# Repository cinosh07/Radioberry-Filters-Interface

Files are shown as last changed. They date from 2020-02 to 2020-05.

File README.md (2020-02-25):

# Radioberry beta V3 - Filters Interface companion module.

Radioberry project
https://github.com/pa3gsb/Radioberry-2.x

This project interface LPF, HPF and T/R Switch to the radiobery I/O over i2c.
The logic is arduino nano v3 based microcontroller.

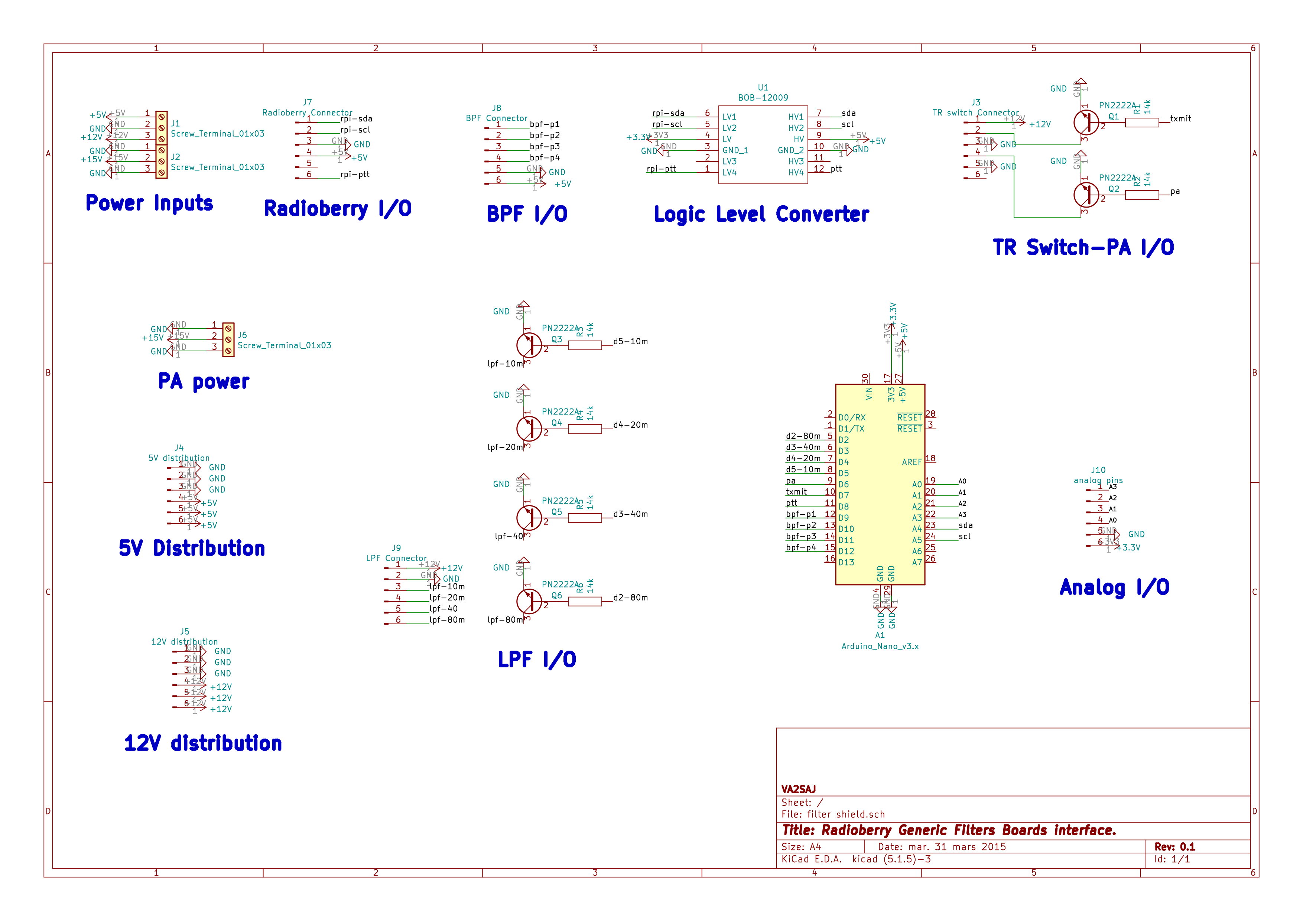
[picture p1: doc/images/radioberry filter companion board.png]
schema


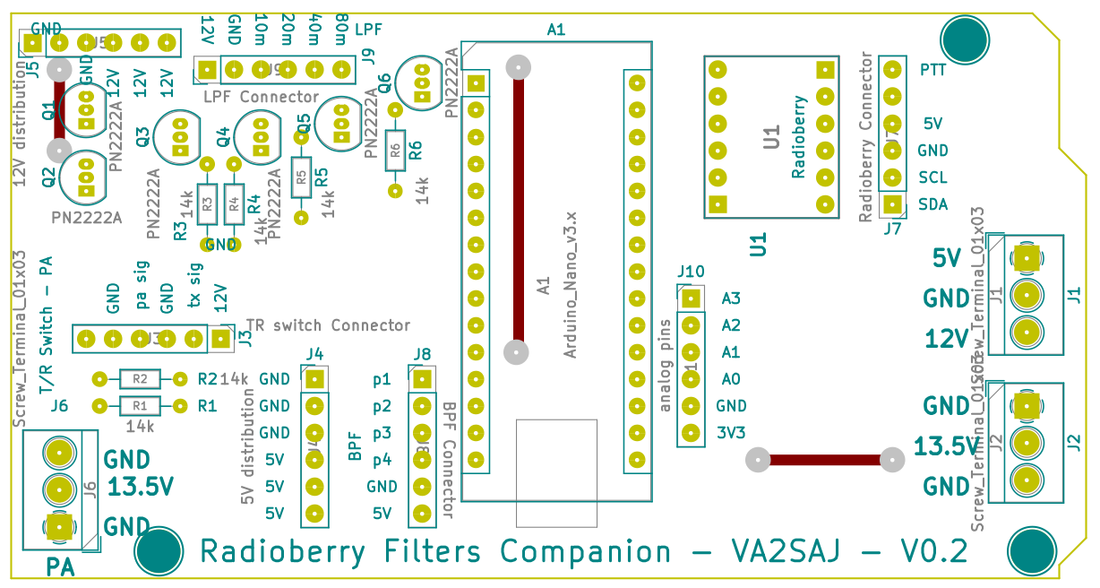
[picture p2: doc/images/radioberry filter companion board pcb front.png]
PCB TOP


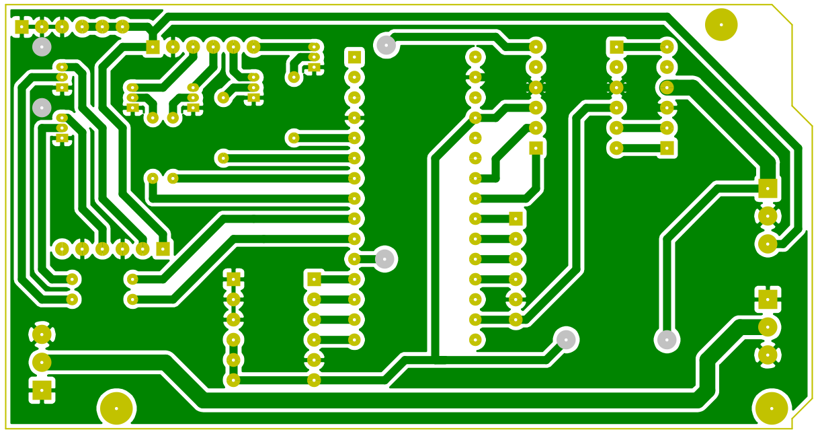
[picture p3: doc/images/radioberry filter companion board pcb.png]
PCB BACK


Band pass filters module supported:
https://www.ebay.ca/itm/HF-BPF-band-pass-filter-RTL-SDR-HERMES-ODYSSEY-HiQSDR-Red-Pitaya-transceiver/332074659425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

Low pass filters module supported:
https://www.ebay.ca/itm/12v-100W-3-5Mhz-30Mhz-HF-power-amplifier-low-pass-filter-Diy-kit/113761898910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

T/R Switch module supported:
https://www.qrpkits.com/ezseries.html#eztrsw

Auto Antenna tuner supported:
https://www.ebay.ca/itm/KIT-DIY-Automatic-Antenna-Tuner-7x7-ATU-100-mini-by-N7DDC/202740242392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

Linear PA supported:
https://www.qrp-labs.com/linear.html

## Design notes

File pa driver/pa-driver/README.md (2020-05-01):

# Radioberry beta V3 RPI4 - 9db PA Driver Module.

Radioberry project
https://github.com/pa3gsb/Radioberry-2.x

This allow to amplify the RPI4 radioberry version TX output, to suitable level for 10W QRP Labs Linear Power Amplifier.

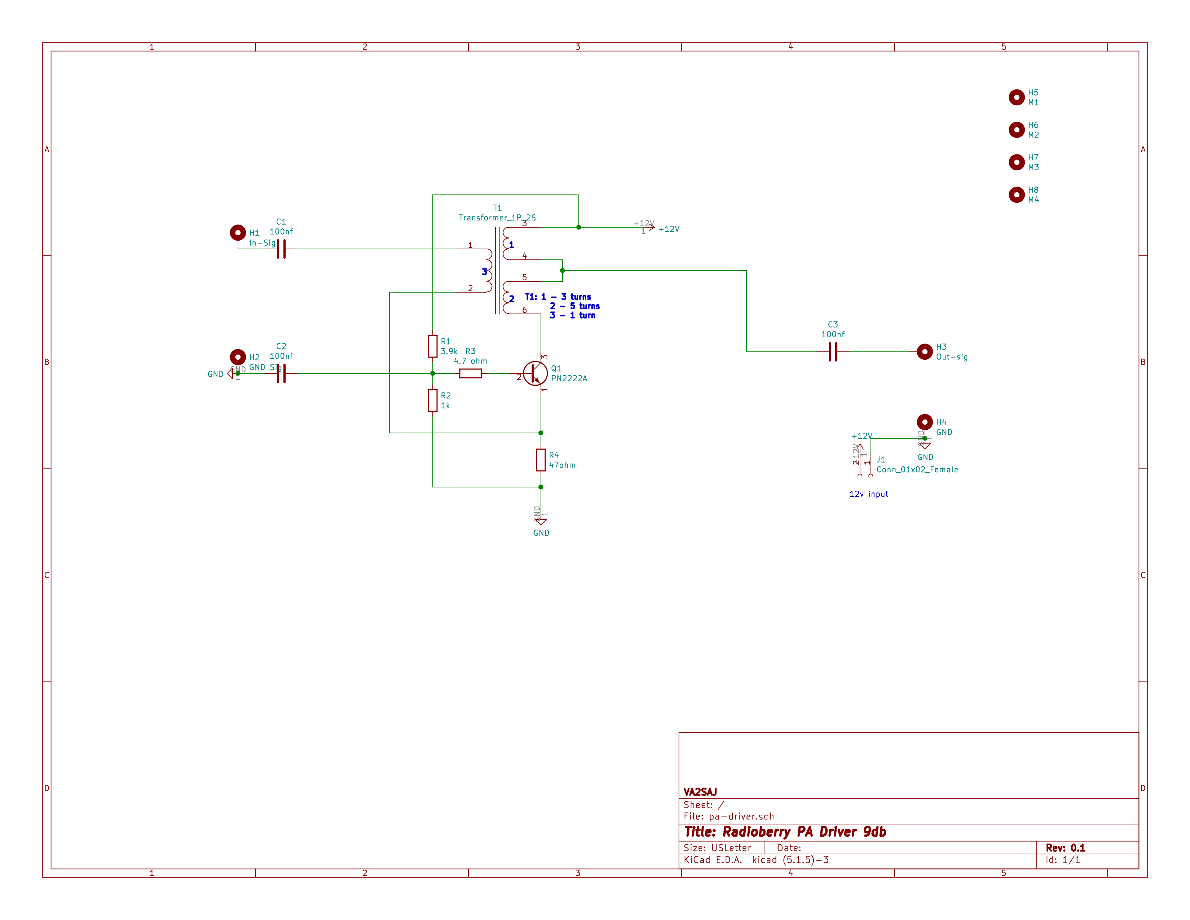
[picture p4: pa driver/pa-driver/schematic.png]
schema


Mesurement.

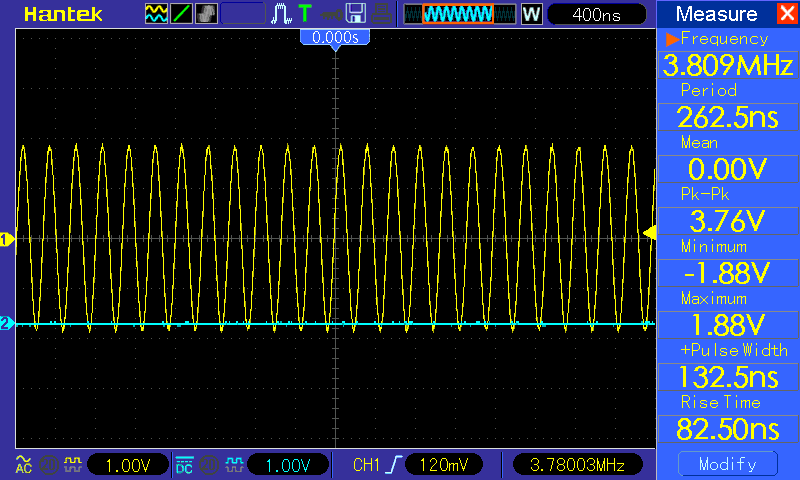
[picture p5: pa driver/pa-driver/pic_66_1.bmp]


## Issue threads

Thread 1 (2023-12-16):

program not working correctly

PE1PWR, 2023-12-16:
Hi m8,
Thanks for sharing your program and PCB board.
Ik have built already the radioberry and controller from Dileep.
My problem is when I connect a hermes on to the Nano I get not the right signals.
160m 0010
80m   0010
40m   0011
30m   0100
20m   0101
17m   0110
15m   0111
12m   0010
10m   0010
160,80,12 and 10m are the same bits so this is not working for the BPF filter board.
Is it so that the ino file on github is not complete? Or must I do something else to get the right signals. I am using the PIHPSDR from Dileep
[VU2DLE/Radioberry_Console: piHPSDR Controller. Is this the right version for your design. I hope you get a solution for me to finish my radioberry project.

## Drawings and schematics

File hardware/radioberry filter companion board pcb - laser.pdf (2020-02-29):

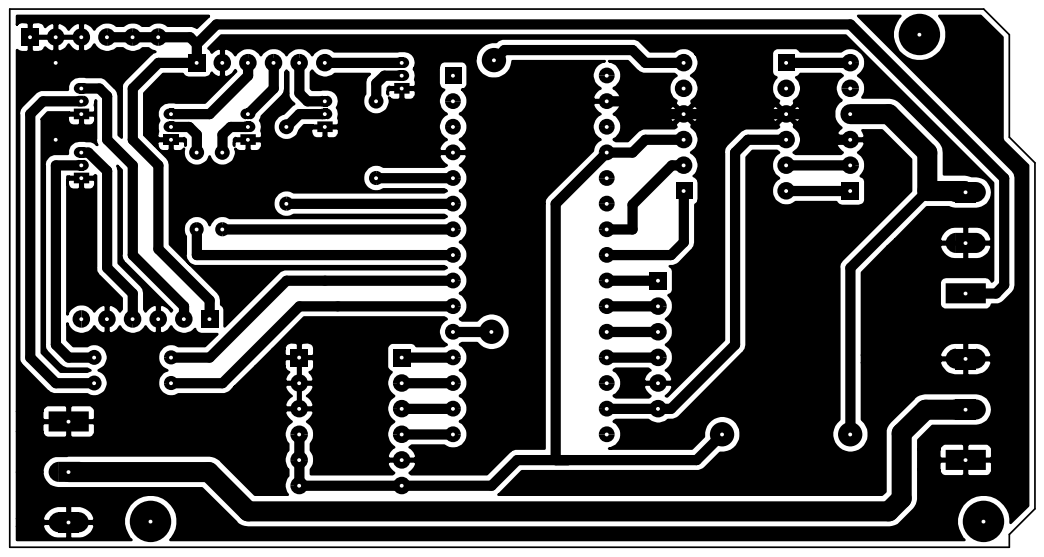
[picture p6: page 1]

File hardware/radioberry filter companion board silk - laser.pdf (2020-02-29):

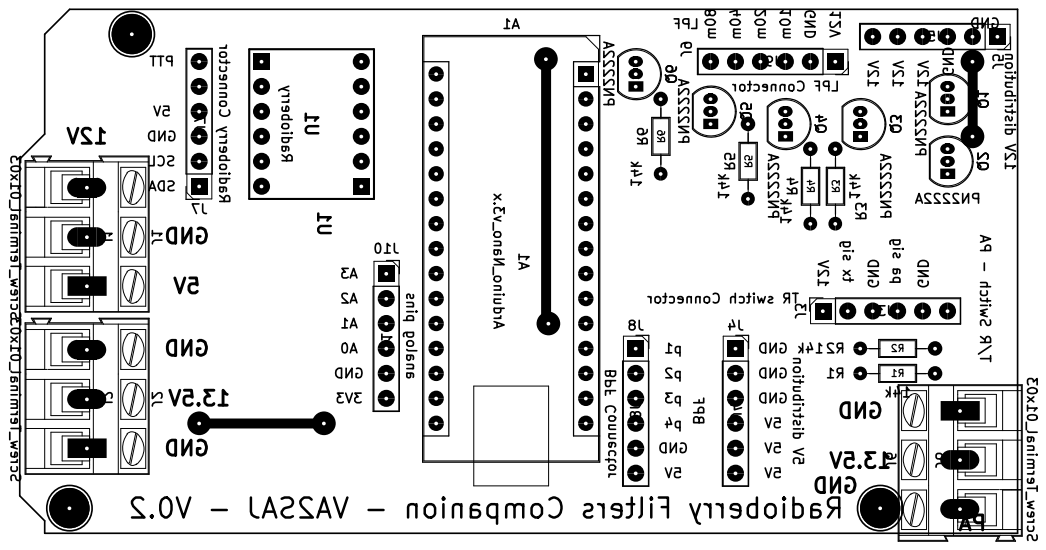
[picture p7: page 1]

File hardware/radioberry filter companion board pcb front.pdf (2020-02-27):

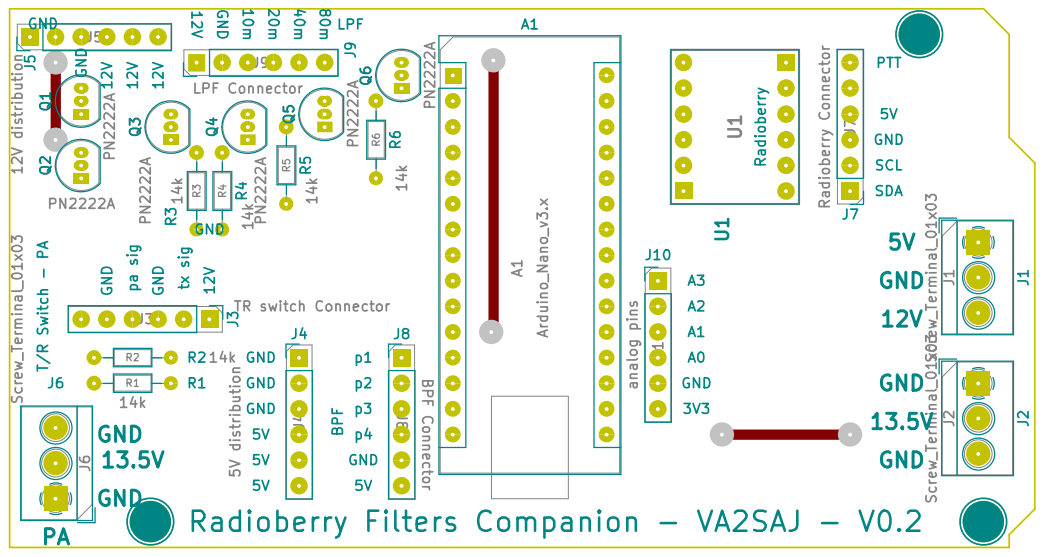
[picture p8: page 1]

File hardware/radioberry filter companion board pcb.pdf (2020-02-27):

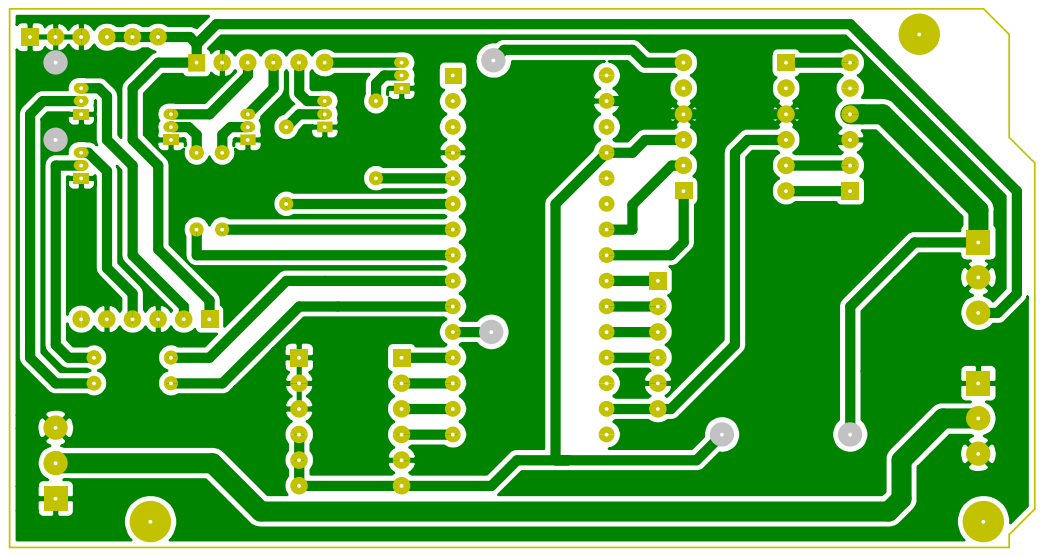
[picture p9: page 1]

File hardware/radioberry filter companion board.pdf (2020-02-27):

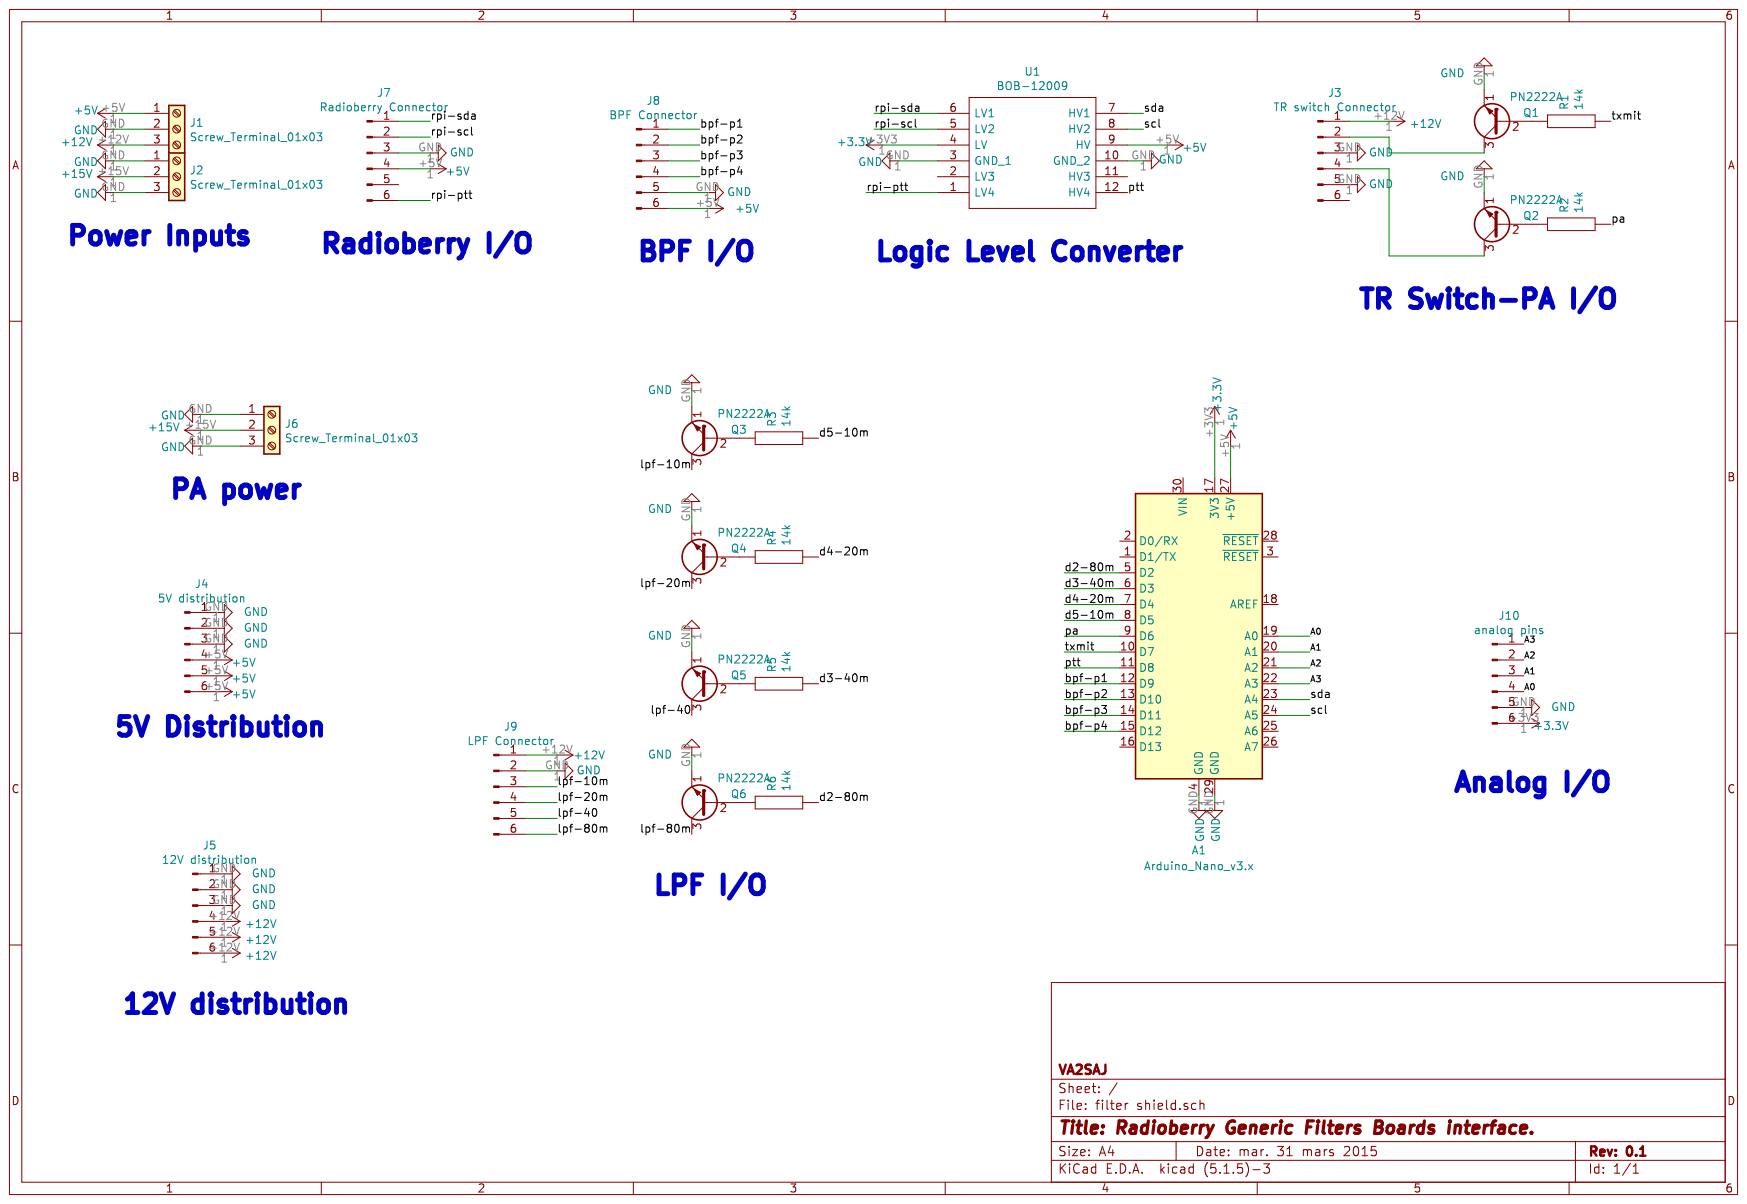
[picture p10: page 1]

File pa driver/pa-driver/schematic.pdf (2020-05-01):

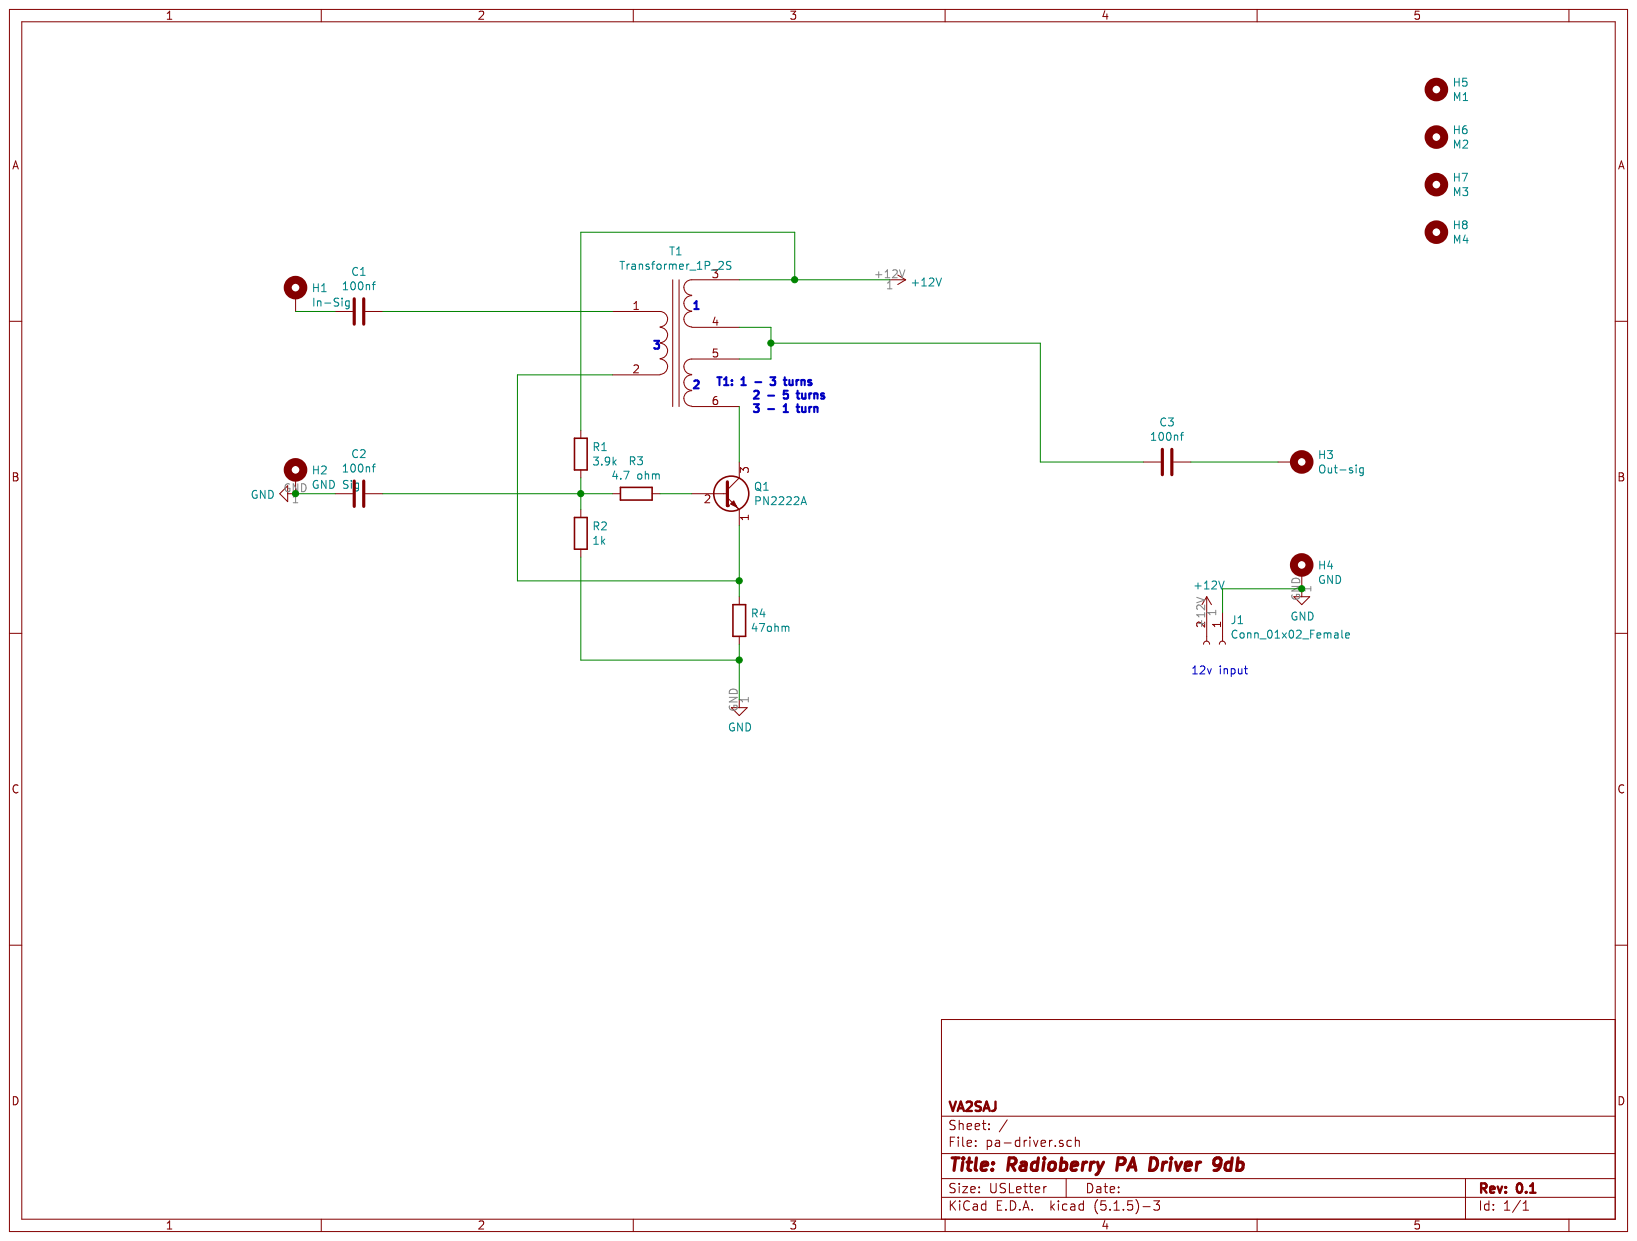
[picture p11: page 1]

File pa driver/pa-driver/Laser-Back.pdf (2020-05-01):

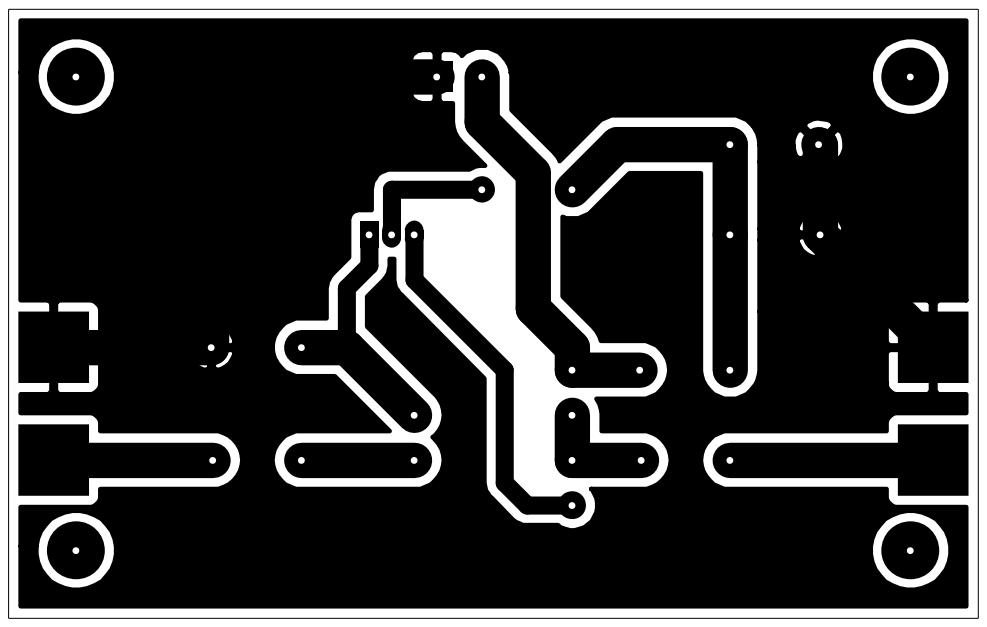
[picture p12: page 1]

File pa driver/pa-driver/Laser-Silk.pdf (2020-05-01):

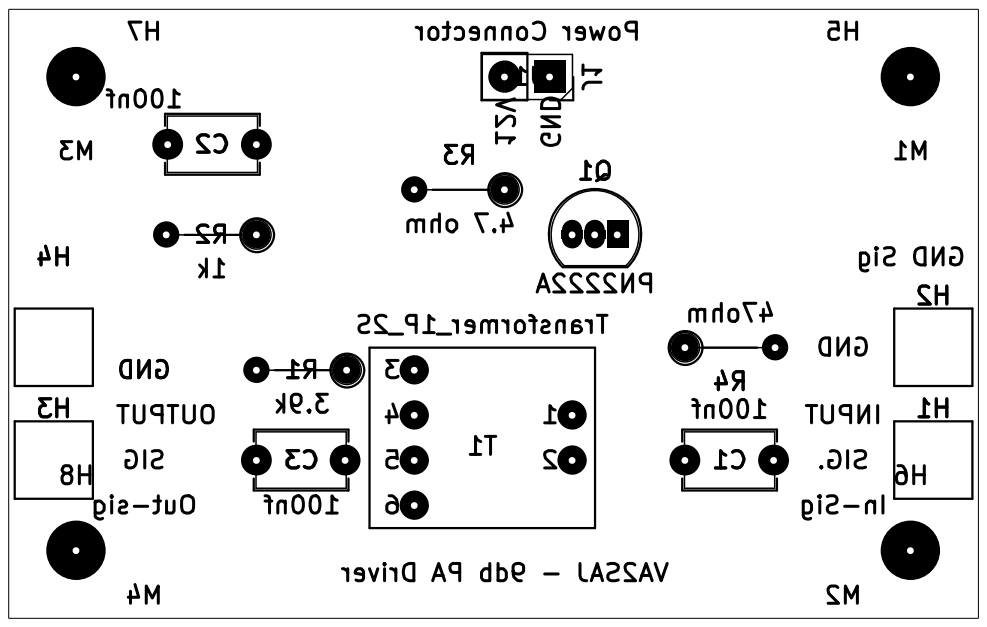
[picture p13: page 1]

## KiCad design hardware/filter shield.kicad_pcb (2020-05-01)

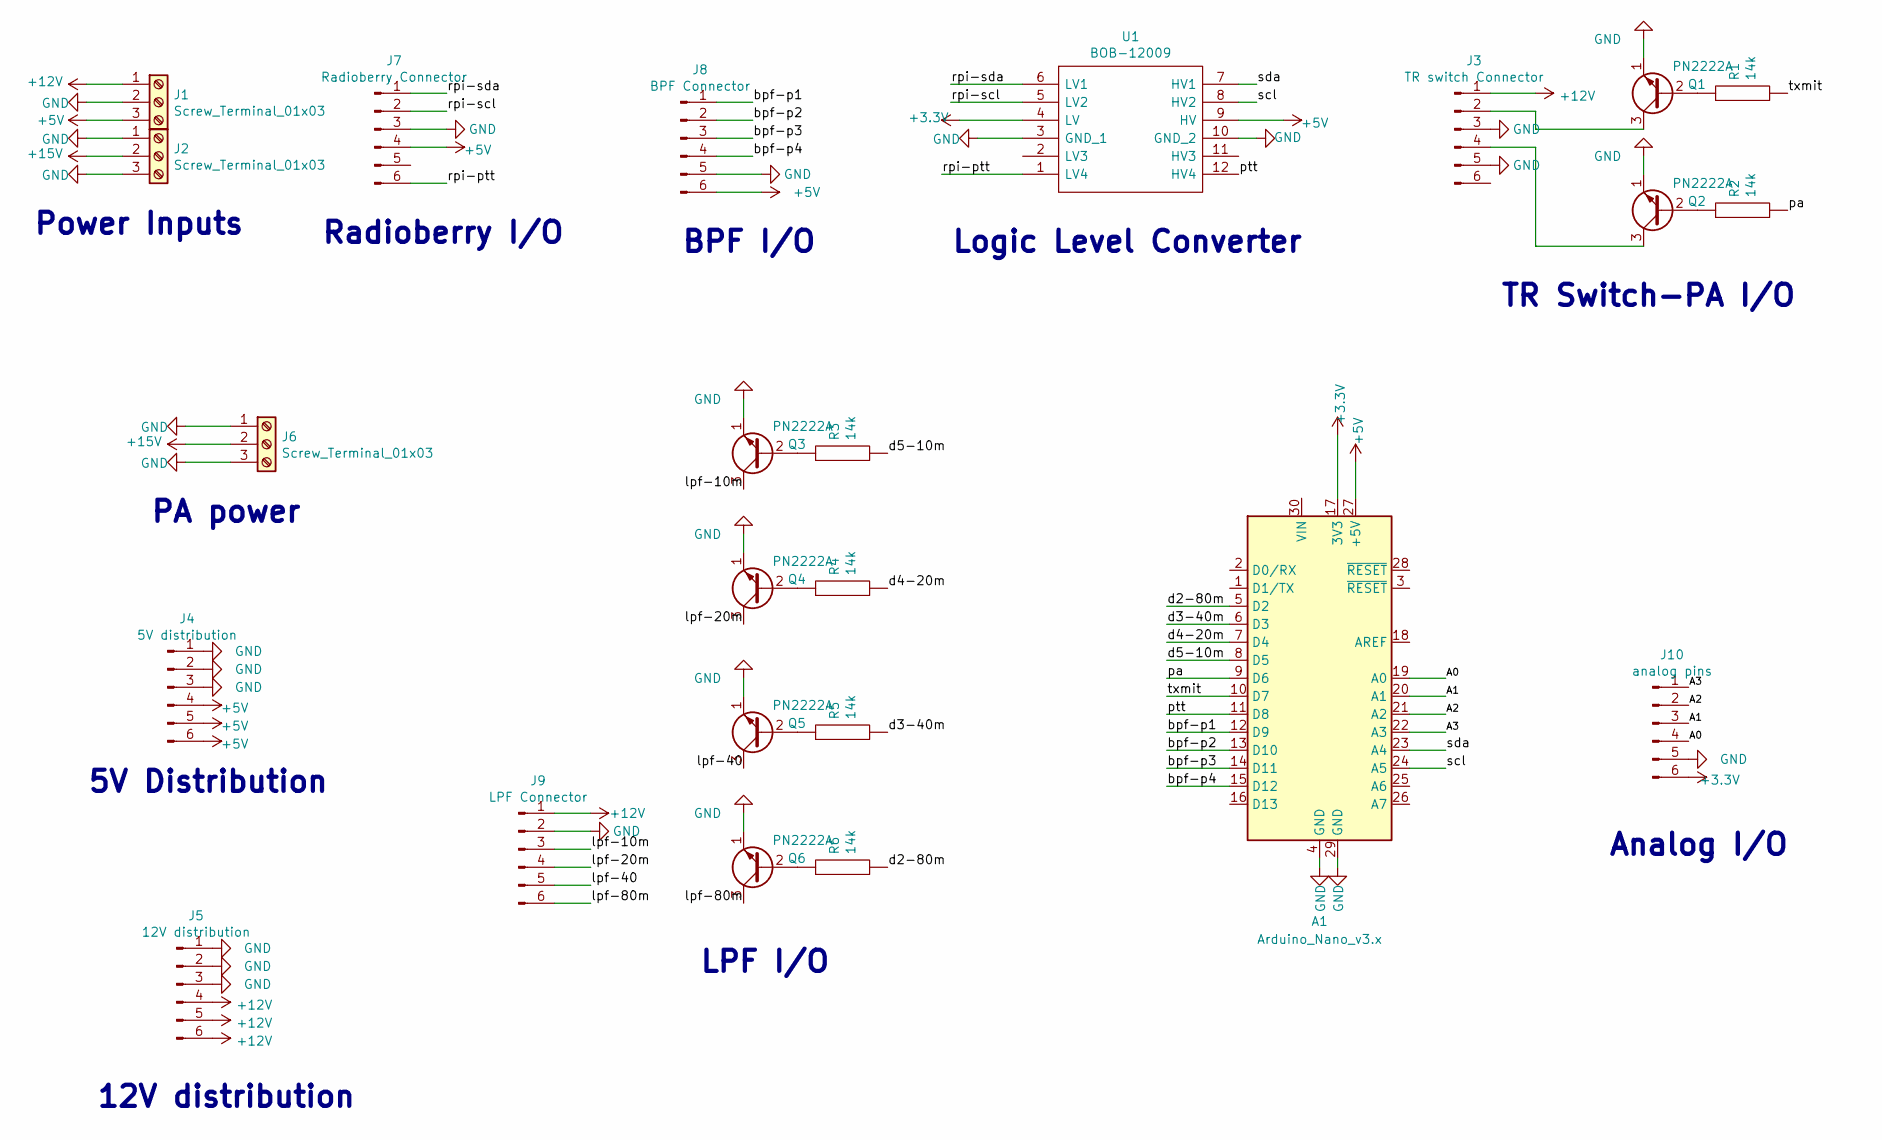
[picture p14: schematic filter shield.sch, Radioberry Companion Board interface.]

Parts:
A1: Arduino_Nano_v3.x; Arduino_Nano
J1, J2, J6: Screw_Terminal_01x03; TerminalBlock_Altech_AK300-3_P5.00mm
J3: TR switch Connector; PinHeader_1x06_P2.54mm_Vertical
J4: 5V distribution; PinHeader_1x06_P2.54mm_Vertical
J5: 12V distribution; PinHeader_1x06_P2.54mm_Vertical
J7: Radioberry Connector; PinHeader_1x06_P2.54mm_Vertical
J8: BPF Connector; PinHeader_1x06_P2.54mm_Vertical
J9: LPF Connector; PinHeader_1x06_P2.54mm_Vertical
J10: analog pins; PinHeader_1x06_P2.54mm_Vertical
Q1, Q2, Q3, Q4, Q5, Q6: PN2222A; TO-92_Inline
R1, R2, R3, R4, R5, R6: 14k; R_Axial_DIN0204_L3.6mm_D1.6mm_P7.62mm_Horizontal
U1: BOB-12009; BOB12009; Mouser Part Number 474-BOB-12009

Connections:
+3V3: A1.17 (3V3), J10.6, U1.4 (LV)
+5V: A1.27 (+5V), J1.3, J4.4, J4.5, J4.6, J7.4, J8.6, U1.9 (HV)
+12V: J1.1, J3.1, J5.4, J5.5, J5.6, J9.1
+15V: J2.2, J6.2
/A0: A1.19 (A0), J10.4
/A1: A1.20 (A1), J10.3
/A2: A1.21 (A2), J10.2
/A3: A1.22 (A3), J10.1
/bpf-p1: A1.12 (D9), J8.1
/bpf-p2: A1.13 (D10), J8.2
/bpf-p3: A1.14 (D11), J8.3
/bpf-p4: A1.15 (D12), J8.4
/d2-80m: A1.5 (D2), R6.2
/d3-40m: A1.6 (D3), R5.2
/d4-20m: A1.7 (D4), R4.2
/d5-10m: A1.8 (D5), R3.2
/lpf-10m: J9.3, Q3.3 (C)
/lpf-20m: J9.4, Q4.3 (C)
/lpf-40: J9.5, Q5.3 (C)
/lpf-80m: J9.6, Q6.3 (C)
/pa: A1.9 (D6), R2.2
/ptt: A1.11 (D8), U1.12 (HV4)
/rpi-ptt: J7.6, U1.1 (LV4)
/rpi-scl: J7.2, U1.5 (LV2)
/rpi-sda: J7.1, U1.6 (LV1)
/scl: A1.24 (A5), U1.8 (HV2)
/sda: A1.23 (A4), U1.7 (HV1)
/txmit: A1.10 (D7), R1.2
GND: A1.4 (GND), A1.29 (GND), J1.2, J2.1, J2.3, J3.3, J3.5, J4.1, J4.2, J4.3, J5.1, J5.2, J5.3, J6.1, J6.3, J7.3, J8.5, J9.2, J10.5, Q1.1 (E), Q2.1 (E), Q3.1 (E), Q4.1 (E), Q5.1 (E), Q6.1 (E), U1.3 (GND_1), U1.10 (GND_2)
unnamed: J3.2, Q1.3 (C)
unnamed: J3.4, Q2.3 (C)
unnamed: Q1.2 (B), R1.1
unnamed: Q2.2 (B), R2.1
unnamed: Q3.2 (B), R3.1
unnamed: Q4.2 (B), R4.1
unnamed: Q5.2 (B), R5.1
unnamed: Q6.2 (B), R6.1

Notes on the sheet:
Power Inputs
Radioberry I/O
BPF I/O
LPF I/O
TR Switch-PA I/O
PA power
Logic Level Converter
Analog I/O
5V Distribution
12V distribution

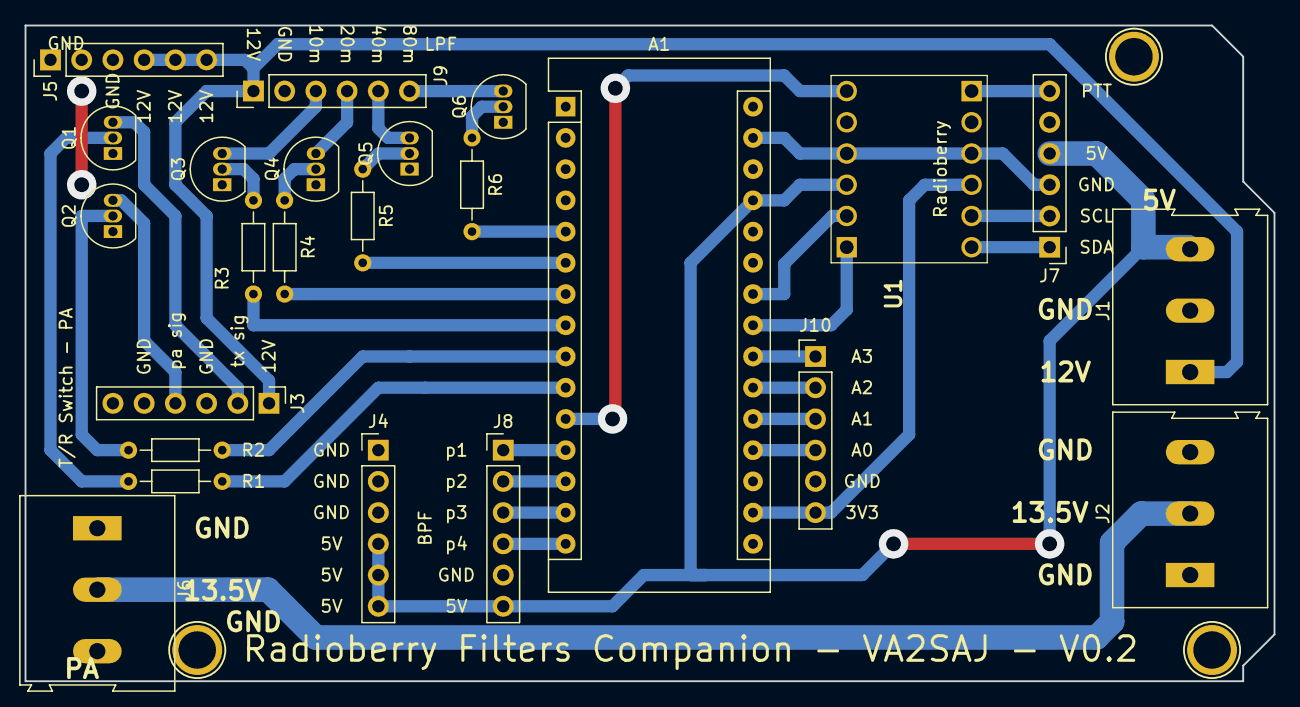
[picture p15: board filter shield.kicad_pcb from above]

Board: 2 copper layers, 101.6 x 53.3 mm, 27 parts (0 on the bottom side), 37 nets.

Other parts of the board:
P8, P10, P13: CONN_01X01; Arduino_1pin

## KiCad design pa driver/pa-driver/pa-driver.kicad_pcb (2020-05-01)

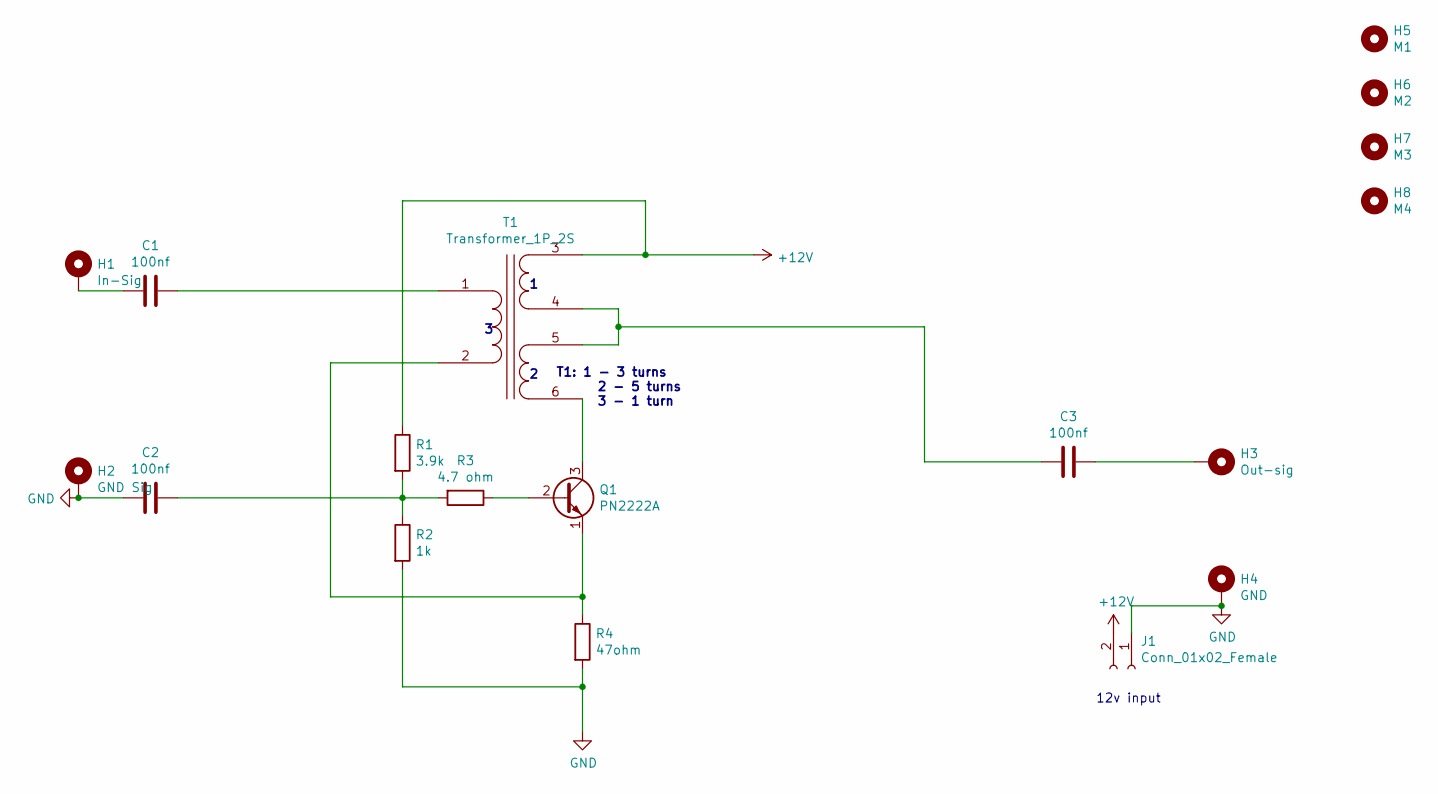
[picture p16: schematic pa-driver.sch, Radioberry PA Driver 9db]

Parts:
C1, C2, C3: 100nf; C_Disc_D5.1mm_W3.2mm_P5.00mm
H1: In-Sig; TestPoint_Pad_4.0x4.0mm
H2: GND Sig; TestPoint_Pad_4.0x4.0mm
H3: Out-sig; TestPoint_Pad_4.0x4.0mm
H4: GND; TestPoint_Pad_4.0x4.0mm
H5: M1; MountingHole_3.2mm_M3
H6: M2; MountingHole_3.2mm_M3
H7: M3; MountingHole_3.2mm_M3
H8: M4; MountingHole_3.2mm_M3
J1: Conn_01x02_Female; PinHeader_1x02_P2.54mm_Vertical
Q1: PN2222A; TO-92_Inline
R1: 3.9k; R_Axial_DIN0204_L3.6mm_D1.6mm_P5.08mm_Vertical
R2: 1k; R_Axial_DIN0204_L3.6mm_D1.6mm_P5.08mm_Vertical
R3: 4.7 ohm; R_Axial_DIN0204_L3.6mm_D1.6mm_P5.08mm_Vertical
R4: 47ohm; R_Axial_DIN0204_L3.6mm_D1.6mm_P5.08mm_Vertical
T1: Transformer_1P_2S; Transformer2 1p 2s Binocular

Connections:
+12V: J1.2, R1.1, T1.3 (SA)
GND: C2.2, H2.1, H4.1, J1.1, R2.2, R4.2
unnamed: C1.1, T1.1 (AA)
unnamed: C1.2, H1.1
unnamed: C2.1, R1.2, R2.1, R3.2
unnamed: C3.1, H3.1
unnamed: C3.2, T1.4 (SB), T1.5 (SC)
unnamed: Q1.1 (E), R4.1, T1.2 (AB)
unnamed: Q1.2 (B), R3.1
unnamed: Q1.3 (C), T1.6 (SD)

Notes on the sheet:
T1: 1 - 3 turns 2 - 5 turns 3 - 1 turn
12v input

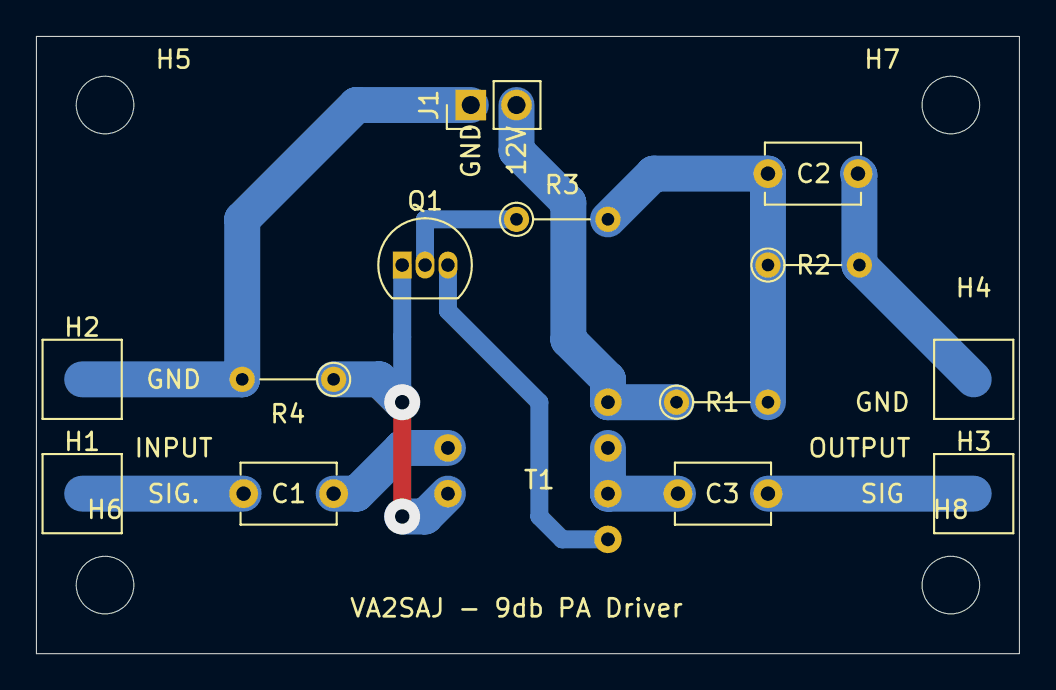
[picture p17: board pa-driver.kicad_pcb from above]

Board: 2 copper layers, 54.6 x 34.3 mm, 18 parts (0 on the bottom side), 10 nets.

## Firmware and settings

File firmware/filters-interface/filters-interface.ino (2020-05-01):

#include <Wire.h>
//const uint8_t I2C_ADDRESS = 0x21; //Alex Board Protocol
const uint8_t I2C_ADDRESS = 0x20; //Generic Board Protocol
uint8_t received;
uint8_t message;
const uint8_t COMMAND_ON_OFF = 0x01;
const uint8_t COMMAND_SPEED = 0x02;

const int FILTER_160M = 8;
const int FILTER_80m = 4;
const int FILTER_60m = 2;
const int FILTER_40m = 802;
const int FILTER_30m = 401;
const int FILTER_20m = 101;
const int FILTER_17m = 164;
const int FILTER_15m = 264;
const int FILTER_12m = 232;
const int FILTER_10m = 232;
const int FILTER_6m = 232;
int currentCW = 0;
boolean genericMode = false;

//#define debug

//Pin definitions
#define lpf_board_xf-lpf-hf
//https://www.ebay.ca/itm/12v-100W-3-5Mhz-30Mhz-HF-power-amplifier-low-pass-filter-Diy-kit/113761898910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
#if defined lpf_board_xf-lpf-hf
int lpf_15_10m = 5;
int lpf_20_17m = 4;
int lpf_40m = 3;
int lpf_80m = 2;
#endif

#define bpf_board_russian
//https://www.ebay.ca/itm/HF-BPF-band-pass-filter-RTL-SDR-HERMES-ODYSSEY-HiQSDR-Red-Pitaya-transceiver/332074659425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
//BPF pins logic definition russian board
//160m 1000
//80m 0100
//40m 1100
//30m 0010
//20m 1010
//17m 0110
//15m 1110
//12m 0001
//10m 1001
#if defined bpf_board_russian
int bpf_pin1 = 9;
int bpf_pin2 = 10;
int bpf_pin3 = 11;
int bpf_pin4 = 12;
#endif

int ptt_pin = 8;
int tx_pin = 7;
int pa_pin = 6;

int currentBand = 0;
boolean transmit = 0;
boolean transmitAllowed = true;

void setup() {

#if defined lpf_board_xf-lpf-hf
  pinMode(lpf_15_10m, OUTPUT);
  pinMode(lpf_20_17m, OUTPUT);
  pinMode(lpf_40m, OUTPUT);
  pinMode(lpf_80m, OUTPUT);
  digitalWrite(lpf_15_10m, LOW);
  digitalWrite(lpf_20_17m, LOW);
  digitalWrite(lpf_40m, LOW);
  digitalWrite(lpf_80m, LOW);
#endif

#if defined bpf_board_russian
  pinMode(bpf_pin1, OUTPUT);
  pinMode(bpf_pin2, OUTPUT);
  pinMode(bpf_pin3, OUTPUT);
  pinMode(bpf_pin4, OUTPUT);
  digitalWrite(bpf_pin1, LOW);
  digitalWrite(bpf_pin2, LOW);
  digitalWrite(bpf_pin3, LOW);
  digitalWrite(bpf_pin4, LOW);
#endif

  //Start i2c as slave
  Wire.begin(I2C_ADDRESS);
  Wire.onRequest(requestEvent);
  Wire.onReceive(receiveEvent);

  pinMode(ptt_pin, INPUT);
  pinMode(tx_pin, OUTPUT);
  digitalWrite(tx_pin, LOW);
  pinMode(pa_pin, OUTPUT);
  digitalWrite(pa_pin, LOW);

#if defined debug
  Serial.begin(115200);
#endif
}
void requestEvent()
{
  if (received == COMMAND_ON_OFF) {

  } else {
    Wire.write(0);
  }
}
int started = 0;
void loop() {

  int ptt = digitalRead(ptt_pin);
  if (ptt == HIGH && currentCW == 1) {
    processPTT(ptt);
  } else if (ptt == LOW && currentCW == 1) {
    processPTT(ptt);
  }
  delay(50);
}
void toggleTxmit(int ptt) {
  if (transmitAllowed == true) {
    transmit = ptt;
    if (ptt == 1) {
      digitalWrite(tx_pin, HIGH);
      digitalWrite(pa_pin, HIGH);
    } else {
      digitalWrite(tx_pin, LOW);
      digitalWrite(pa_pin, LOW);
    }
  }
}
void receiveEvent(int bytes) {

  int byteCount = 0;
  int command = 0;
  uint8_t byte1 = 0;
  uint8_t byte2 = 0;
  uint8_t byte3 = 0;
  int freqHigh [8] = {0, 0, 0, 0, 0, 0, 0, 0};
  while (0 < Wire.available()) {
    byte x = Wire.read();
    if (genericMode == false) {
      if (byteCount == 0) {
        byte1 = x;
      }
      if (byteCount == 1) {
        byte2 = x;
        command = command + (byte2 * 100);
      }
      if (byteCount == 2) {
        byte3 = x;
        command = command + byte3;
      }
      if (byte1 == 2 && byte2 == 2 && byte3 == 3) {
        genericMode = true;
        byte1 = 0;
        //#if defined debug
        //        Serial.println("Generic Mode set to true");
        //#endif
      }
      byteCount = byteCount + 1;
    } else {

      if (byteCount == 0) {
        byte1 = x;
      }
      if (byteCount == 1) {
        byte2 = x;
        command = command + (byte2 * 100);
      }
      if (byteCount == 2) {
        byte3 = x;
        command = command + byte3;
      }

      if (byteCount > 0) {
        freqHigh[byteCount - 1] = x;
      }

      byteCount = byteCount + 1;
    }
  }

#if defined debug
  Serial.print("Command Status: ");
  Serial.println(command);
  Serial.print("Byte1 Status: ");
  Serial.println(byte1);
  Serial.print("Byte2 Status: ");
  Serial.println(byte2);
  Serial.print("Byte3 Status: ");
  Serial.println(byte3);
  Serial.print("freq Received: ");
  Serial.print(freqHigh[0]);
  Serial.print(freqHigh[1]);
  Serial.print(freqHigh[2]);
  Serial.print(freqHigh[3]);
  Serial.print(freqHigh[4]);
  Serial.print(freqHigh[5]);
  Serial.print(freqHigh[6]);
  Serial.println(freqHigh[7]);
#endif
  int pttTrig = digitalRead(ptt_pin);
  if (byte1 == 3 && pttTrig == HIGH && byte2 > 0) {
    currentCW = byte3;
    processPTT(byte2);
    command = 0;
  } else if (byte1 == 3 && pttTrig == HIGH && byte3 > 0) {
    currentCW = byte3;
    processPTT(byte3);
    command = 0;
  } else if (byte1 == 3) {
    currentCW = byte3;
    processPTT(0);

  } else {
    currentCW = 0;
    processPTT(0);
  }
  if (byte1 == 4) {
    processFrequency(freqHigh);
    command = 0;

  }
  if (command != 0) {
#if defined debug
    Serial.print("Command Sended: ");
    Serial.println(command);
#endif
    processCommand(command);
  }

}
void processPTT(int command) {
  digitalWrite(tx_pin, command);
  digitalWrite(pa_pin, command);
}
void processFrequency(int command) {

}
void processCommand(int command) {
  started =  1;
  if (currentBand != command) {
    currentBand = command;
    switch (command) {
      case FILTER_160M:
#if defined bpf_board_russian
        digitalWrite(bpf_pin1, HIGH);
        digitalWrite(bpf_pin2, LOW);
        digitalWrite(bpf_pin3, LOW);
        digitalWrite(bpf_pin4, LOW);
#endif
#if defined lpf_board_xf-lpf-hf
        //Not supported
        digitalWrite(lpf_15_10m, LOW);
        digitalWrite(lpf_20_17m, LOW);
        digitalWrite(lpf_40m, LOW);
        digitalWrite(lpf_80m, LOW);
#endif
        break;
      case FILTER_80m:
#if defined bpf_board_russian
        digitalWrite(bpf_pin1, LOW);
        digitalWrite(bpf_pin2, HIGH);
        digitalWrite(bpf_pin3, LOW);
        digitalWrite(bpf_pin4, LOW);
#endif
#if defined lpf_board_xf-lpf-hf
        digitalWrite(lpf_15_10m, LOW);
        digitalWrite(lpf_20_17m, LOW);
        digitalWrite(lpf_40m, LOW);
        digitalWrite(lpf_80m, HIGH);
#endif
        break;
      case FILTER_60m:
#if defined bpf_board_russian
        //Not supported
        digitalWrite(bpf_pin1, LOW);
        digitalWrite(bpf_pin2, LOW);
        digitalWrite(bpf_pin3, LOW);
        digitalWrite(bpf_pin4, LOW);
#endif
#if defined lpf_board_xf-lpf-hf
        //Not supported
        digitalWrite(lpf_15_10m, LOW);
        digitalWrite(lpf_20_17m, LOW);
        digitalWrite(lpf_40m, LOW);
        digitalWrite(lpf_80m, LOW);
#endif
        break;
      case FILTER_40m:
#if defined bpf_board_russian
        digitalWrite(bpf_pin1, HIGH);
        digitalWrite(bpf_pin2, HIGH);
        digitalWrite(bpf_pin3, LOW);
        digitalWrite(bpf_pin4, LOW);
#endif
#if defined lpf_board_xf-lpf-hf
        digitalWrite(lpf_15_10m, LOW);
        digitalWrite(lpf_20_17m, LOW);
        digitalWrite(lpf_40m, HIGH);
        digitalWrite(lpf_80m, LOW);
#endif
        break;
      case FILTER_30m:
#if defined bpf_board_russian
        digitalWrite(bpf_pin1, LOW);
        digitalWrite(bpf_pin2, LOW);
        digitalWrite(bpf_pin3, HIGH);
        digitalWrite(bpf_pin4, LOW);
#endif
#if defined lpf_board_xf-lpf-hf
        //Not supported
        digitalWrite(lpf_15_10m, LOW);
        digitalWrite(lpf_20_17m, LOW);
        digitalWrite(lpf_40m, LOW);
        digitalWrite(lpf_80m, LOW);
#endif
        break;
      case FILTER_20m:
#if defined bpf_board_russian
        digitalWrite(bpf_pin1, HIGH);
        digitalWrite(bpf_pin2, LOW);
        digitalWrite(bpf_pin3, HIGH);
        digitalWrite(bpf_pin4, LOW);
#endif
#if defined lpf_board_xf-lpf-hf
        digitalWrite(lpf_15_10m, LOW);
        digitalWrite(lpf_20_17m, HIGH);
        digitalWrite(lpf_40m, LOW);
        digitalWrite(lpf_80m, LOW);
#endif
        break;
      case FILTER_17m:
#if defined bpf_board_russian
        digitalWrite(bpf_pin1, LOW);
        digitalWrite(bpf_pin2, HIGH);
        digitalWrite(bpf_pin3, HIGH);
        digitalWrite(bpf_pin4, LOW);
#endif
#if defined lpf_board_xf-lpf-hf
        digitalWrite(lpf_15_10m, LOW);
        digitalWrite(lpf_20_17m, HIGH);
        digitalWrite(lpf_40m, LOW);
        digitalWrite(lpf_80m, LOW);
#endif
        break;
      case FILTER_15m:
#if defined bpf_board_russian
        digitalWrite(bpf_pin1, HIGH);
        digitalWrite(bpf_pin2, HIGH);
        digitalWrite(bpf_pin3, HIGH);
        digitalWrite(bpf_pin4, LOW);
#endif
#if defined lpf_board_xf-lpf-hf
        digitalWrite(lpf_15_10m, HIGH);
        digitalWrite(lpf_20_17m, LOW);
        digitalWrite(lpf_40m, LOW);
        digitalWrite(lpf_80m, LOW);
#endif
        break;
      case FILTER_12m:
#if defined bpf_board_russian
        digitalWrite(bpf_pin1, LOW);
        digitalWrite(bpf_pin2, LOW);
        digitalWrite(bpf_pin3, LOW);
        digitalWrite(bpf_pin4, HIGH);
#endif
#if defined lpf_board_xf-lpf-hf
        digitalWrite(lpf_15_10m, HIGH);
        digitalWrite(lpf_20_17m, LOW);
        digitalWrite(lpf_40m, LOW);
        digitalWrite(lpf_80m, LOW);
#endif
        break;
      //                case FILTER_10m:
      //                        #if defined bpf_board_russian
      //                        digitalWrite(bpf_pin1, HIGH);
      //                        digitalWrite(bpf_pin2, LOW);
      //                        digitalWrite(bpf_pin3, LOW);
      //                        digitalWrite(bpf_pin4, HIGH);
      //                        #endif
      //                        #if defined lpf_board_xf-lpf-hf
      //                        digitalWrite(lpf_15_10m, HIGH);
      //                        digitalWrite(lpf_20_17m, LOW);
      //                        digitalWrite(lpf_40m, LOW);
      //                        digitalWrite(lpf_80m, LOW);
      //                        #endif
      //                        break;
      //                case FILTER_6m:
      //                        #if defined bpf_board_russian
      //                        digitalWrite(bpf_pin1, LOW);
      //                        digitalWrite(bpf_pin2, LOW);
      //                        digitalWrite(bpf_pin3, LOW);
      //                        digitalWrite(bpf_pin4, LOW);
      //                        #endif
      //                        #if defined lpf_board_xf-lpf-hf
      //                        digitalWrite(lpf_15_10m, LOW);
      //                        digitalWrite(lpf_20_17m, LOW);
      //                        digitalWrite(lpf_40m, LOW);
      //                        digitalWrite(lpf_80m, LOW);
      //                        #endif
      //                        break;
      default:
        //TODO Disable TX
        //Wire.write(0);
#if defined bpf_board_russian
        digitalWrite(bpf_pin1, LOW);
        digitalWrite(bpf_pin2, HIGH);
        digitalWrite(bpf_pin3, LOW);
        digitalWrite(bpf_pin4, LOW);
#endif
#if defined lpf_board_xf-lpf-hf
        digitalWrite(lpf_15_10m, LOW);
        digitalWrite(lpf_20_17m, LOW);
        digitalWrite(lpf_40m, LOW);
        digitalWrite(lpf_80m, HIGH);
#endif
        break;
    }
  }
}

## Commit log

2020-02-19 Hardware Kitcad files
    [filter shield.kicad_pcb, filter shield.sch]
2020-02-19 Arduino firmware
2020-02-20 tr switch circuit added
    [filter shield.kicad_pcb, filter shield.sch]
2020-02-21 First version completed and ready to etch.
    [filter shield.kicad_pcb]
2020-02-25 Small corrections
    [filter shield.kicad_pcb, filter shield.sch]
2020-02-27 Revised circuit to meet lpf protocol. Added futur expansion i/o over analog pins
    [filter shield.sch]
2020-02-27 Small changes
    [filter shield.kicad_pcb, filter shield.sch]
2020-02-27 Modif to silk
    [filter shield.kicad_pcb]
2020-02-29 Change screw terminal to 5mm footprint
    [filter shield.kicad_pcb, filter shield.sch]
2020-03-01 Modif to pin assignment
2020-03-02 Modif to error in the silk of pcb
    [filter shield.kicad_pcb]
2020-03-04 Added 9db pa driver schematics
    [pa-driver.kicad_pcb, pa-driver.sch]
2020-03-09 9db PA Driver modification
    [pa-driver.sch]
2020-04-21 Modif to PA driver
    [pa-driver.kicad_pcb, pa-driver.sch]
